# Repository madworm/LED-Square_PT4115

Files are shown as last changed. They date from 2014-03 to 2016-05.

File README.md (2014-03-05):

LED-Square_PT4115
=================

LAYOUT FILES: 50x50mm LED-Square with PT4115 LED driver.

LED type: Nichia NT2x757DT

---

Before having PC-boards made, please make sure you know about your manufacturer's peculiarities!
Especially drill-sizes and their tolerances may vary too much and give you trouble.

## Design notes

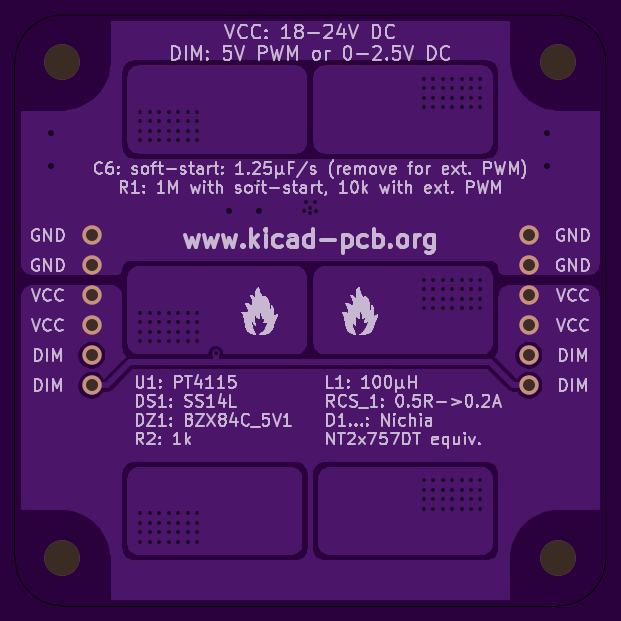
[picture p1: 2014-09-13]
gerber_files/PNGs/LED-Square_PT4115__back_purple.png

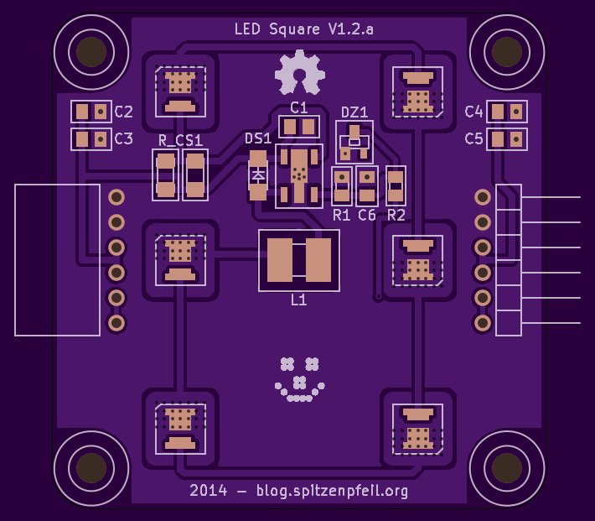
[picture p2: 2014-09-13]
gerber_files/PNGs/LED-Square_PT4115__front_purple.png

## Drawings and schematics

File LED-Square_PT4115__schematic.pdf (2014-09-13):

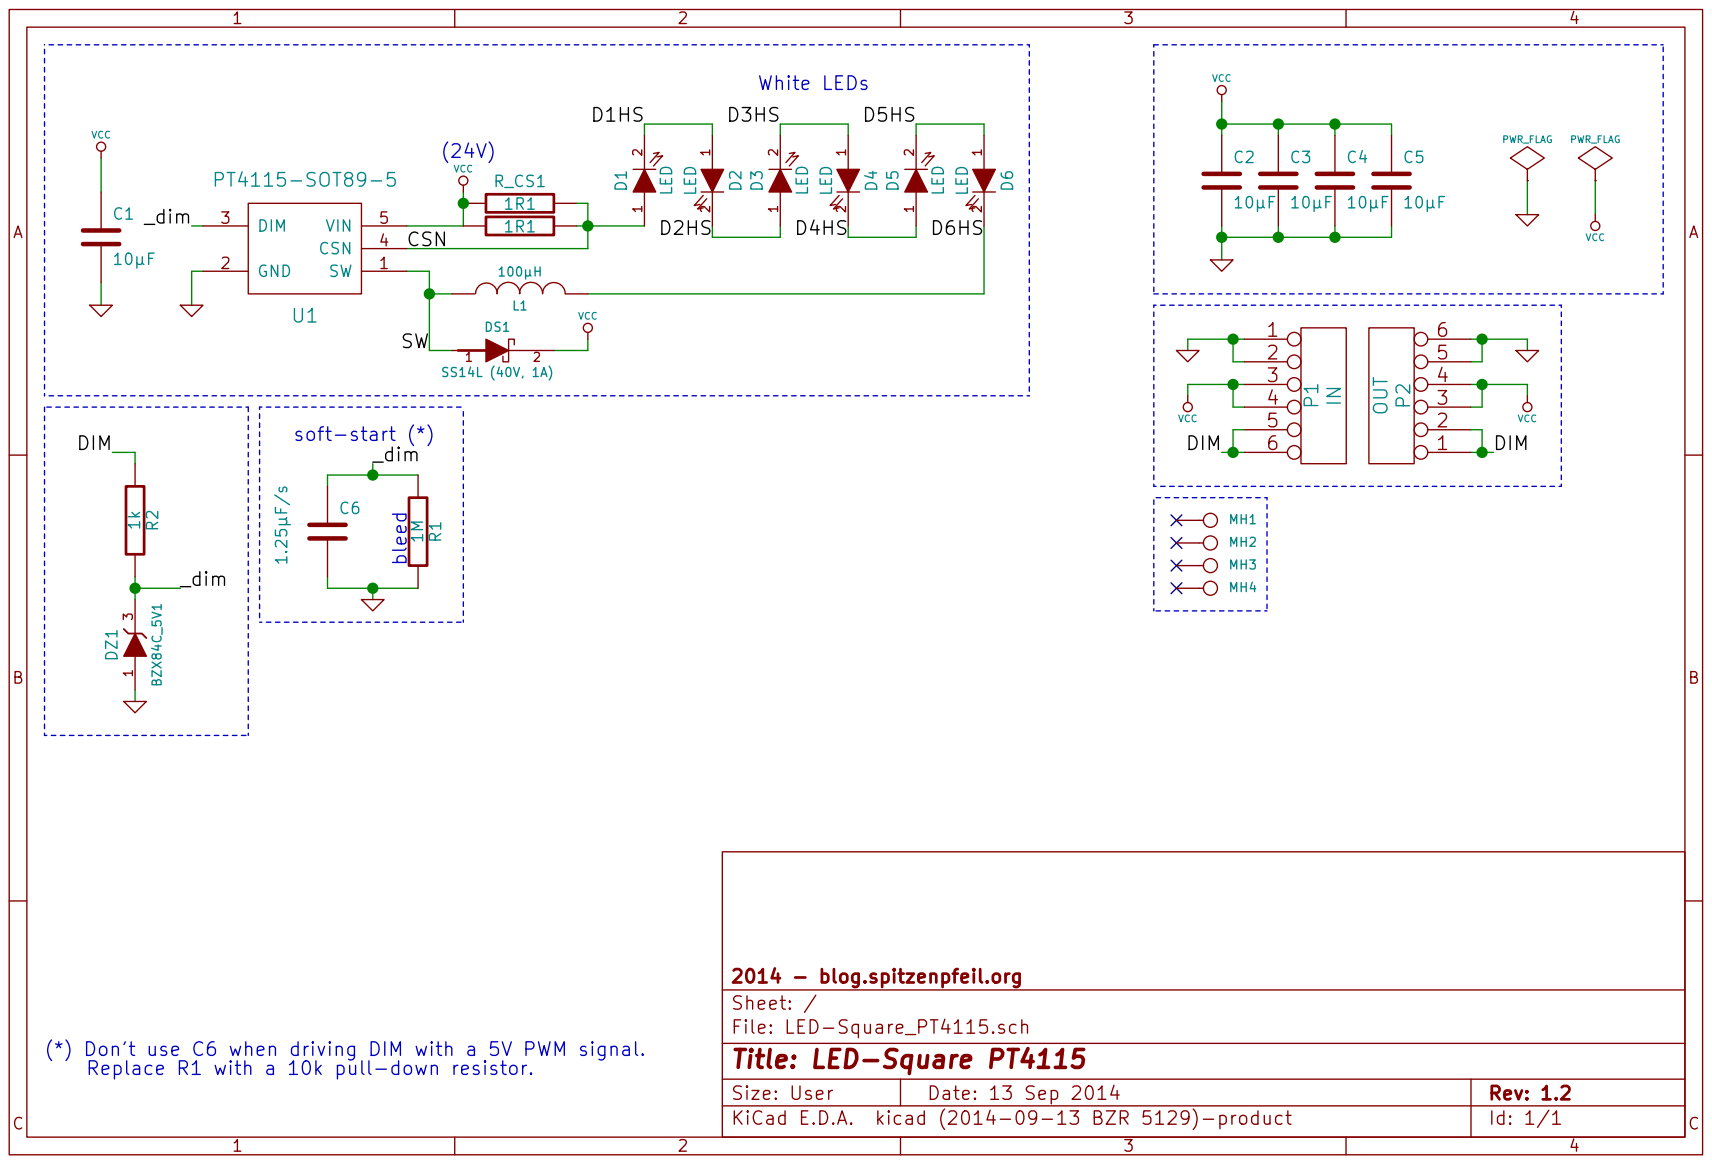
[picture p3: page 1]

File: LED-Square_PT4115.sch Sheet: / 2014 - blog.spitzenpfeil.org

(*) Don't use C6 when driving DIM with a 5V PWM signal.
Replace R1 with a 10k pull-down resistor.

Id: 1/1 Title: LED-Square PT4115

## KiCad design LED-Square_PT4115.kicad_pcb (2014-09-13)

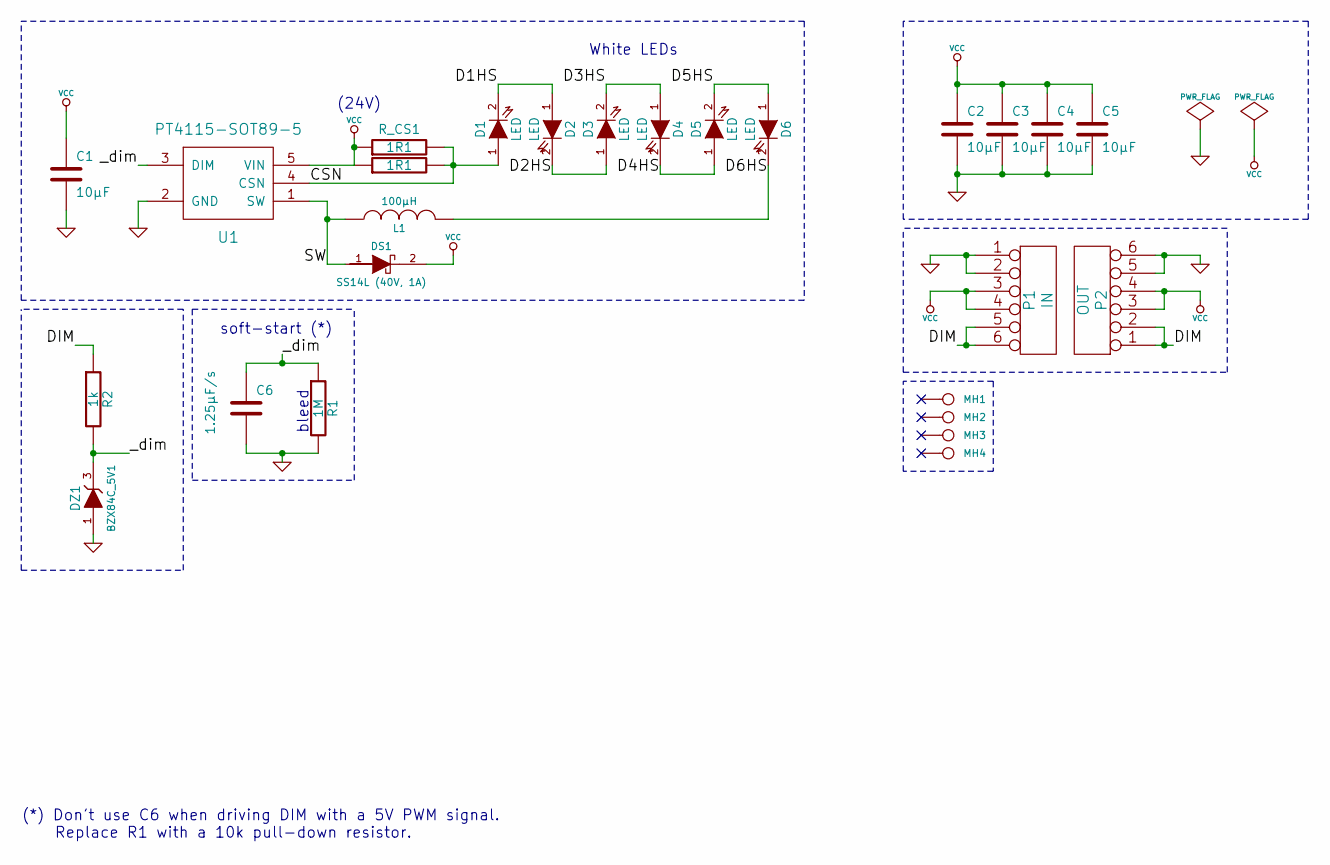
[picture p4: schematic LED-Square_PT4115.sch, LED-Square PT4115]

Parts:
C1, C2, C3, C4, C5: 10µF
C6: 1.25µF/s
D1, D2, D3, D4, D5, D6: LED
DS1: SS14L (40V, 1A)
DZ1: BZX84C_5V1
L1: 100µH
MH1, MH2, MH3, MH4: CONN_1
P1: IN
P2: OUT
R1: 1M
R2: 1k
R_CS1, R_CS2: 1R1
U1: PT4115-SOT89-5

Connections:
/CSN: D1.1 (A), R_CS1.2, R_CS2.2, U1.4 (CSN)
/D1HS: D1.2 (K), D2.1 (A)
/D2HS: D2.2 (K), D3.1 (A)
/D3HS: D3.2 (K), D4.1 (A)
/D4HS: D4.2 (K), D5.1 (A)
/D5HS: D5.2 (K), D6.1 (A)
/D6HS: D6.2 (K), L1.2
/DIM: P1.5, P1.6, P2.1, P2.2, R2.1
/SW: DS1.1 (A), L1.1, U1.1 (SW)
/_dim: C6.1, DZ1.3, R1.1, R2.2, U1.3 (DIM)
GND: C1.2, C2.2, C3.2, C4.2, C5.2, C6.2, DZ1.1, P1.1, P1.2, P2.5, P2.6, R1.2, U1.2 (GND)
VCC: C1.1, C2.1, C3.1, C4.1, C5.1, DS1.2 (C), P1.3, P1.4, P2.3, P2.4, R_CS1.1, R_CS2.1, U1.5 (VIN)

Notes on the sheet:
bleed
soft-start (*)
(24V)
White LEDs
(*) Don't use C6 when driving DIM with a 5V PWM signal. Replace R1 with a 10k pull-down resistor.

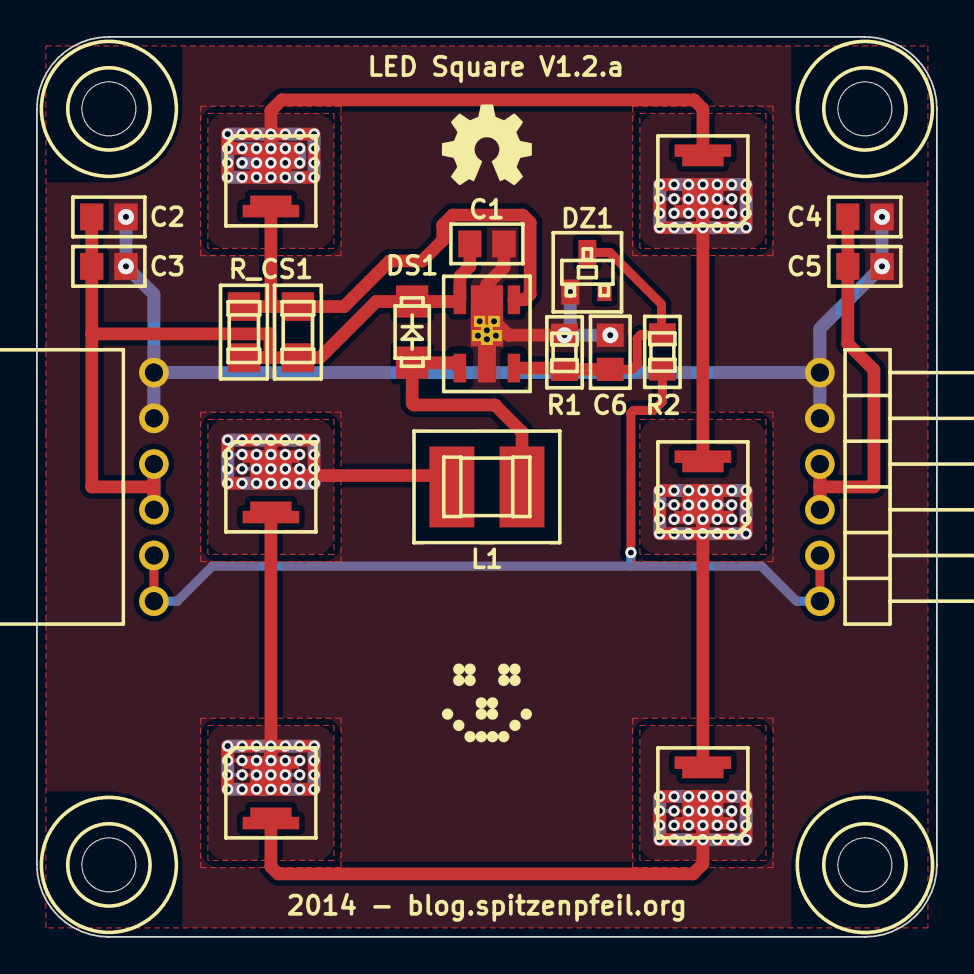
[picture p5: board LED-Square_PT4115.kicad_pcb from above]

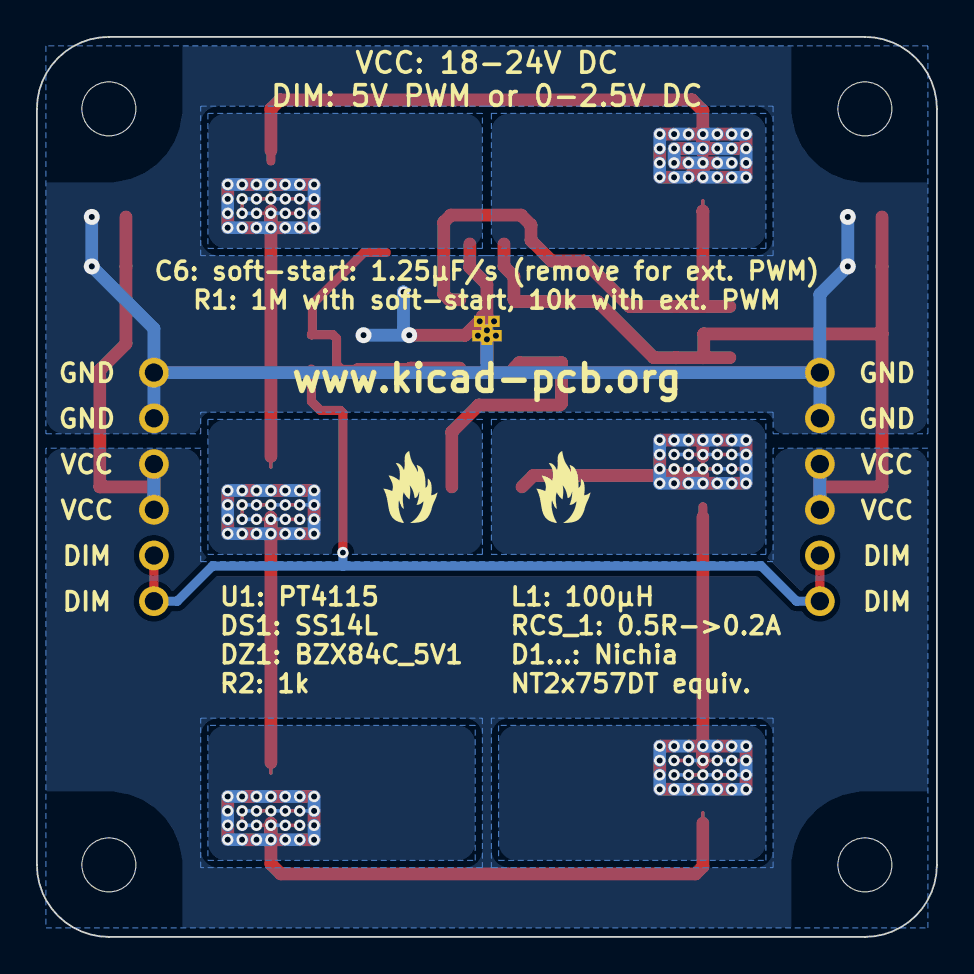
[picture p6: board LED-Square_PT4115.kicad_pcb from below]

Board: 2 copper layers, 50.0 x 50.0 mm, 30 parts (2 on the bottom side), 12 nets.

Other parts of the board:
G1: OSHW-logo_silkscreen_5mm
G2: LED_smile_silkscreen_5mm
G3, G4: fire_silkscreen-back_4mm

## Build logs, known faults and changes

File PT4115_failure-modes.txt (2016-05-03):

PT4115 failure modes:
=====================

* Busted DIM pin. This one REALLY needs over-voltage protection!
  (5.1V Zener diode + dropper resistor)

  Observed manifestations:

  - LOW resistance from DIM to GND (6 Ohm, or 30-ish Ohm)
  - LEDs are permanently on + massive overcurrent
  - LEDs are permanently off

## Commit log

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2012-10-05 Mounting holes might be useful later...
    [LED-Square_PT4115.brd]
2012-10-05 Had to modifiy the NSS-LED footprint for better hand-soldering...
    [LED-Square_PT4115.brd]
2012-10-05 Next step: add power connector(s) and maybe a pot for on-board dimming.
    [LED-Square_PT4115.brd, LED-Square_PT4115.sch]
2012-10-06 Rounded board edges + 42mm mounting hole spacing ;-)
    [LED-Square_PT4115.brd]
2012-10-06 Added copper pour as LED heatsinks.
    [LED-Square_PT4115.brd, LED-Square_PT4115.sch]
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2012-10-22 Added board-to-board connectors.
    [LED-Square_PT4115.brd, LED-Square_PT4115.sch]
2012-10-23 Added board name + Rev. No. and made a few silkscreen tweaks.
    [LED-Square_PT4115.brd]
2012-10-23 Changed the inductor footprint pad size to 2.5 x 4.5mm.
    The inductor should be 1812, but it is much wider. More like 1816.
    Not sure if that officially exists...
    [LED-Square_PT4115.brd]
2012-10-23 Added more copper pour for passive LED cooling + stitching vias.
    [LED-Square_PT4115.brd]
2012-10-23 Some more copper pour tweaks + shifting vias around.
    [LED-Square_PT4115.brd]
2012-10-23 Copper pour tweaks.
    [LED-Square_PT4115.brd]
2012-10-23 Changed the board outline width to 5 mil.
    [LED-Square_PT4115.brd]
2012-10-23 Moved a trace.
    [LED-Square_PT4115.brd]
2012-10-24 Added a few more caps on the supply rail.
    [LED-Square_PT4115.brd, LED-Square_PT4115.sch]
2012-10-24 Shifted C2-C5 around.
    [LED-Square_PT4115.brd]
2012-10-24 Increased pad-size of board-to-board connectors.
    [LED-Square_PT4115.brd]
2012-10-25 Created a PDF for the schematic + gerber files.
    [LED-Square_PT4115-Back.gbl, LED-Square_PT4115-Front.gtl, LED-Square_PT4115-Mask_Back.gbs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]
2012-10-27 Added soft-start capacitor(s) - optional.
    [LED-Square_PT4115.brd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]
2012-10-29 Last tweaks (I hope).
    [LED-Square_PT4115.brd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]
2012-10-29 Well... some more tweaks.
    [LED-Square_PT4115.brd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]
2012-10-29 Halloween-style silkscreen.
    [LED-Square_PT4115.brd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]
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2012-10-30 Playing with gerbmerge again.
    Still it doesn't translate the silkscreen in the final output...
    [layout1.cfg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]
2012-11-07 Added a logo for KiCad + weblink on the back silkscreen.
    [LED-Square_PT4115.brd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]
2012-11-10 Soft-start: replaced C7 with R1 (1M bleed resistor) for remaining C6.
    R1 is not strictly necessary, but it speeds up discharging C6 a lot.
    Without R1 it takes some time, maybe minutes, until soft-start
    works again.
    [LED-Square_PT4115.brd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]
2012-11-10 Upgraded back silkscreen. VCC 18-24V DC.
    [LED-Square_PT4115.brd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]
2012-11-11 Added a 5.6V Zener to protect the PT4115's DIM input. It badly needs it.
    Upped schematic + pcb revision to V0.2
    [LED-Square_PT4115.brd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]
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2012-11-12 Rerouted the DIM track.
    [LED-Square_PT4115.brd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]
2012-11-12 Changed the thermal vias of the SOT89-5 package.
    Requires a more recent version of pcbnew to recognize that the GND
    pads overlap and don't need any connecting tracks.
    [LED-Square_PT4115.brd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]
2012-11-12 Tweaks. Started using KiCad Bazaar revision 3752.
    [LED-Square_PT4115.brd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]
2012-11-13 Back silkscreen updated with info regarding PWM and C6 (soft-start).
    [LED-Square_PT4115.brd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]
2012-11-13 Added info regarding PWM-ing DIM and C6 to the schematic.
    [LED-Square_PT4115.sch]
2012-11-13 Added info to schematic / back silk regarding soft-start vs. ext. PWM.
    [LED-Square_PT4115.brd, LED-Square_PT4115.sch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]
2012-11-13 Shifted a few vias around.
    [LED-Square_PT4115.brd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]
2012-11-15 Renamed a few gerber-files to match KiCad's new layer names.
    [LED-Square_PT4115-B_Mask.gbs, LED-Square_PT4115-B_SilkS.gbo, LED-Square_PT4115-Edge_Cuts.gbr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]
2012-11-18 V1.0: Changed LED orientation + rerouted most of the board + new copper pour.
    [LED-Square_PT4115.brd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]
2012-11-18 Small copper pour correction (around mounting holes) + SS tweak.
    [LED-Square_PT4115.brd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]
2012-11-20 Prototype worked well with 1k + 5V1 Zener, so switched to that.
    [LED-Square_PT4115.brd, LED-Square_PT4115.sch]
2012-12-12 Renamed some gerbmerge related stuff.
    [LED-Square_PT4115-B_Mask.gbs, LED-Square_PT4115-B_SilkS.gbo, LED-Square_PT4115-Edge_Cuts.gbr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]
2013-01-02 Played with the copper pour a bit.
    [LED-Square_PT4115.brd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]
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2013-01-23 Increased drill size for pin-headers to 40mil.
    Did NOT recreate gerber files!
    [LED-Square_PT4115.brd]
2013-01-23 Recreated the gerber files (40mil drill size issue).
    [LED-Square_PT4115-B_Mask.gbs, LED-Square_PT4115-B_SilkS.gbo, LED-Square_PT4115-Back.gbl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]
2013-02-22 Changed the thermal copper pour a bit. Didn't recreate gerbers.
    [LED-Square_PT4115.brd]
2013-02-22 Copper pour + silkscreen tweaks.
    [LED-Square_PT4115.brd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]
2013-06-28 Converted to new kicad board format.
    [LED-Square_PT4115.brd, LED-Square_PT4115.kicad_pcb]
2014-01-14 Fixed silkscreen issues introduced by recent pcbnew 2-line-text-box 'fixes'.
    [LED-Square_PT4115-B_Cu.gbl, LED-Square_PT4115-B_Mask.gbs, LED-Square_PT4115-B_SilkS.gbo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]
2014-03-05 Fooling around a bit.
    [LED-Square_PT4115-B_Cu.gbl, LED-Square_PT4115-B_Mask.gbs, LED-Square_PT4115-B_SilkS.gbo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]
2014-03-05 R_CS --> 1206. Couldn't get 1R1 in 0805.
    [LED-Square_PT4115-B_Cu.gbl, LED-Square_PT4115-B_Mask.gbs, LED-Square_PT4115-B_SilkS.gbo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]
2014-03-06 Used B_Cu as heatsink again.
    [LED-Square_PT4115-B_Cu.gbl, LED-Square_PT4115-B_Mask.gbs, LED-Square_PT4115-B_SilkS.gbo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]
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2014-03-07 More thermal vias for LEDs.
    [LED-Square_PT4115-B_Cu.gbl, LED-Square_PT4115-B_Mask.gbs, LED-Square_PT4115-B_SilkS.gbo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]
2014-03-19 Added 3D shapes for the board-interconnects.
    [LED-Square_PT4115.kicad_pcb]
2014-03-19 Adapted to changed footprint 'MADW__edge-connector_SIL6_female'.
    [LED-Square_PT4115-B_Cu.gbl, LED-Square_PT4115-B_Mask.gbs, LED-Square_PT4115-B_SilkS.gbo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]
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2014-09-13 Now using 2 pins for the DIM signal as well.
    [LED-Square_PT4115-B_Cu.gbl, LED-Square_PT4115-B_Mask.gbs, LED-Square_PT4115-B_SilkS.gbo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]
2016-05-03 5.6V Zener --> 5.1V Zener in '...failure-modes.txt'.
